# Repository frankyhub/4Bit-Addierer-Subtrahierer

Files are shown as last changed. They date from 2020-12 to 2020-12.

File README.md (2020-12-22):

# 4Bit-Addierer-Subtrahierer

## Frontplatte


## Funktion
Ist der Schalter Add in Position oben, werden die 4 Bits a1-a8 mit den Bits b1-b8 addiert und das Ergebnis mit den LEDs S1 - S16 angezeigt.
Ist der Schalter Add in Position unten, werden die 4 Bits b1-b8 von den Bits a1-a8 subtrahiert und das Ergebnis mit den LEDs S1 - S16 angezeigt.

## Schaltplan
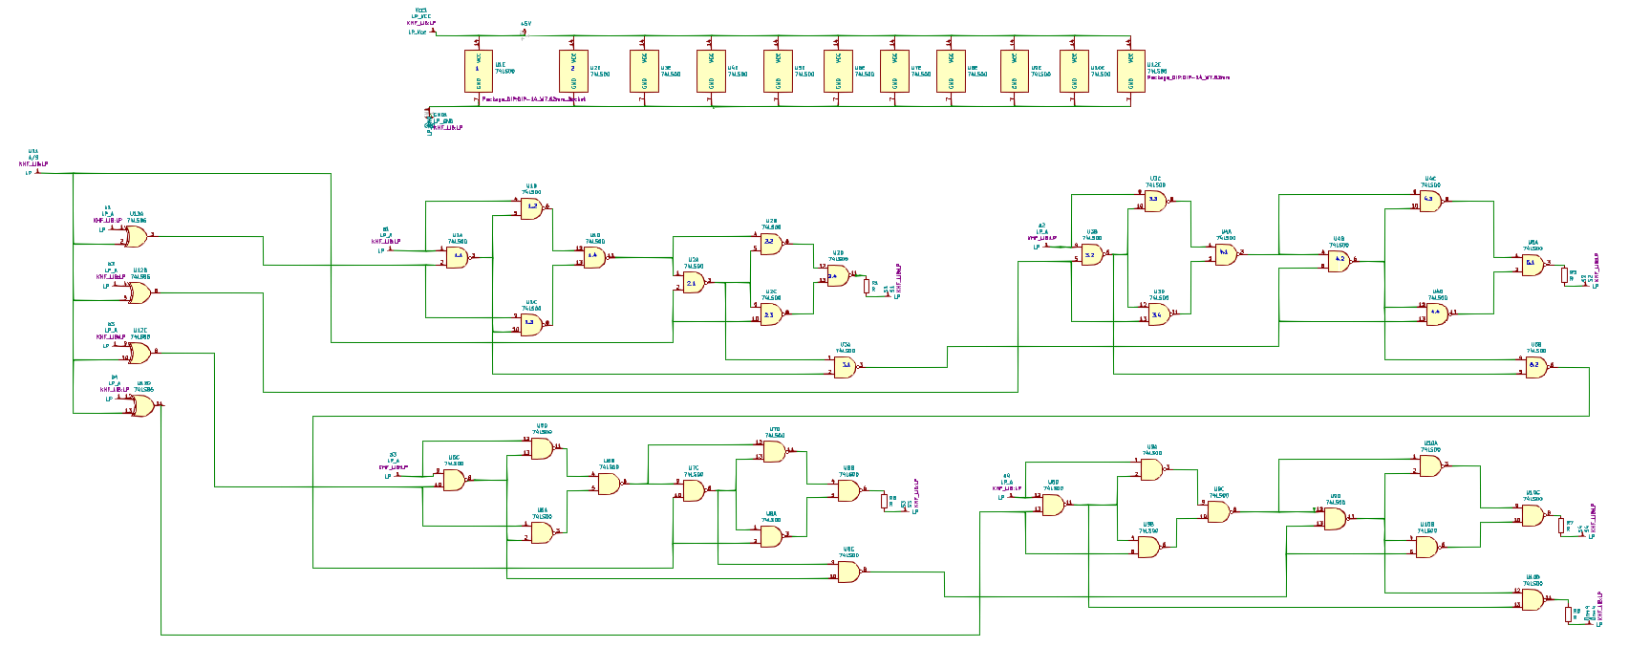
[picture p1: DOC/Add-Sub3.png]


## Platine


## Dokumentation
[Link zur Dokumentation](https://github.com/frankyhub/4Bit-Addierer-Subtrahierer/blob/main/DOC/4-Bit-Add-Sub-Dokumentation.pdf)

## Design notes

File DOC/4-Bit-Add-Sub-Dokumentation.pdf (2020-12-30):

### 4-Bit-Addierer-Subtrahierer

### Dokumentation

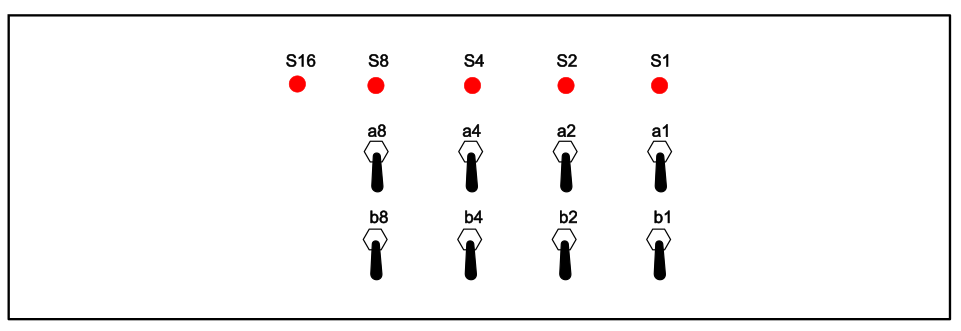
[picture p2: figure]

4-Bit-Addierer-Subtrahierer

Erstellt: | KHF | Version: | V1.0 | Seite 2 von 8

D:\gittemp\4Bit-Addierer\4-Bit-Add-Sub-Dokumentation.docx

Beschreibung

Der 4-Bit-Addierer addiert die Bits a1-a8 mit b1-b8 und zeigt die Summe im dualen Zahlensystem mit den LEDs S1-S16 an. Die Beschriftung der Schalter und LEDs resultiert aus der Wertigkeit der Schalter und der LEDs.

Schalter | Wertigkeit binär | Wertigkeit dezimal
a1 | 2 0 | 1
a2 | 2 1 | 2
a4 | 2 2 | 4
a8 | 2 3 | 8
Schalter | Wertigkeit binär | Wertigkeit dezimal
b1 | 0 2 | 1
b2 | 2 1 | 2
b4 | 2 2 | 4
b8 | 3 2 | 8
LED Summe | Wertigkeit binär | Wertigkeit dezimal
S1 | 2 0 | 1
S2 | 2 1 | 2
S4 | 2 2 | 4
S8 | 2 3 | 8
S16 | 4 2 | 16

Schalterstellung unten = 0, Schalterstellung oben = 1

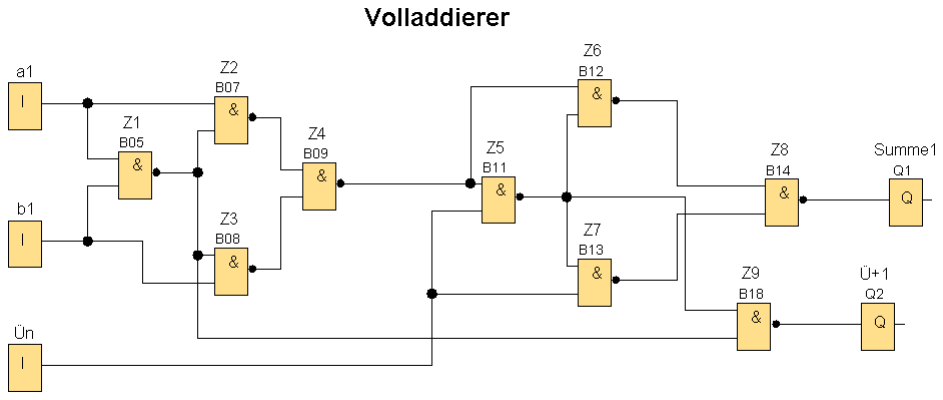
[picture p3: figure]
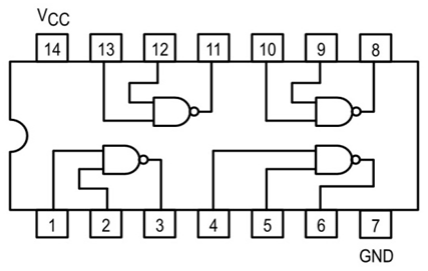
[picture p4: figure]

Erstellt: | KHF | Version: | V1.0 | Seite 3 von 8

Der 4-Bitt-Addierer besteht aus vier Volladdierer:

Ün | a | b | Summe | Ün+1
0 | 0 | 0 | 0 | 0
0 | 0 | 1 | 1 | 0
0 | 1 | 0 | 1 | 0
0 | 1 | 1 | 0 | 1
1 | 0 | 0 | 1 | 0
1 | 0 | 1 | 0 | 1
1 | 1 | 0 | 0 | 1
1 | 1 | 1 | 1 | 1
Funktionstabelle eines Volladdierers

Der 4-Bit-Addierer wurde mit zehn TTL (Transistor-Transistor-Logik) ICs SN74LS00N aufgebaut:

Datasheet SN74LS00N - 4 NAND-Gatter

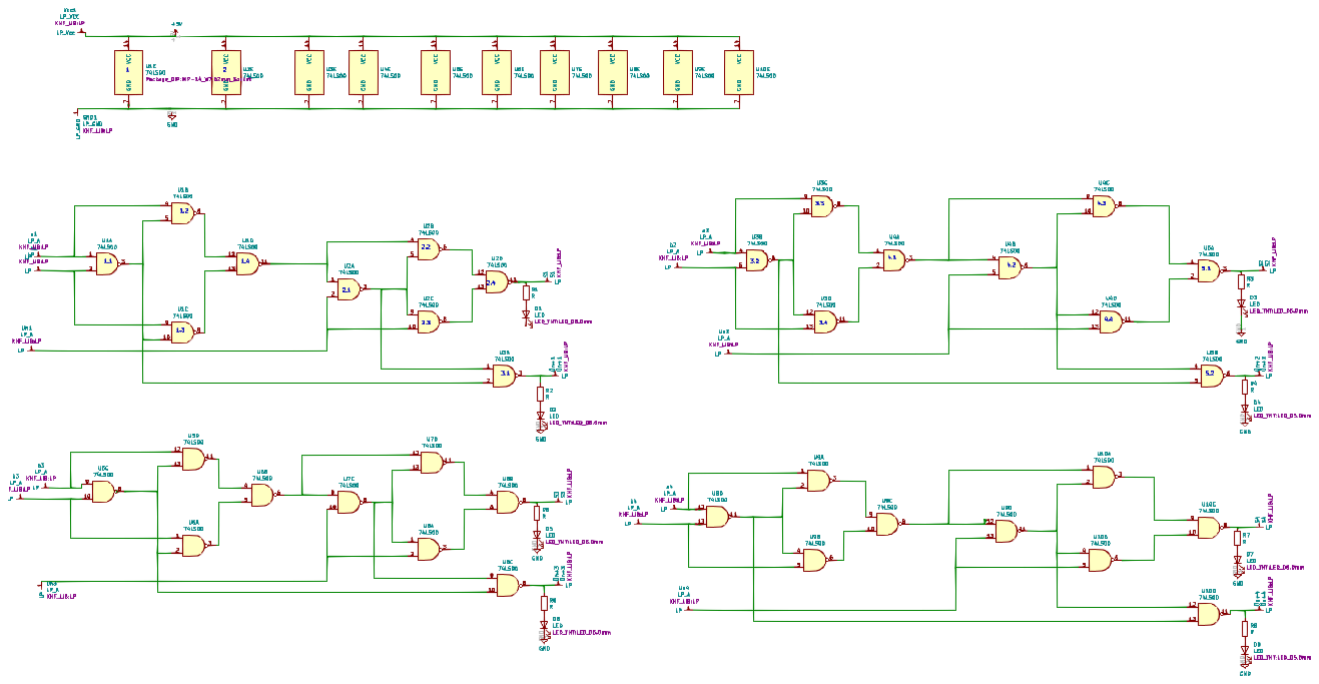
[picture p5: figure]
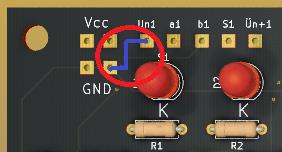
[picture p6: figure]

Erstellt: | KHF | Version: | V1.0 | Seite 4 von 8
Eingang 1 | Eingang 2 | Ausgang
0 | 0 | 1
0 | 1 | 1
0 | 0 | 1
1 | 1 | 0
Funktionstabelle NAND SN74LS00N

Damit die Bits a1-a8 mit den Bits b1-b8 addiert werden können, benötigt man vier Volladdierer.

Schaltplan des 4-Bit-Addierers

Bestehend aus vier Volladdierer

Hinweis: TTL-Bausteine haben die Eigenschaft, einen offenen Eingang als logisch 1 zu erkennen. Deshalb muss der Übertrag Un1 des ersten Addierers mit logisch 0 beschalten werden. Dies erfolgte auf der Platine mit einer Drahtbrücke.

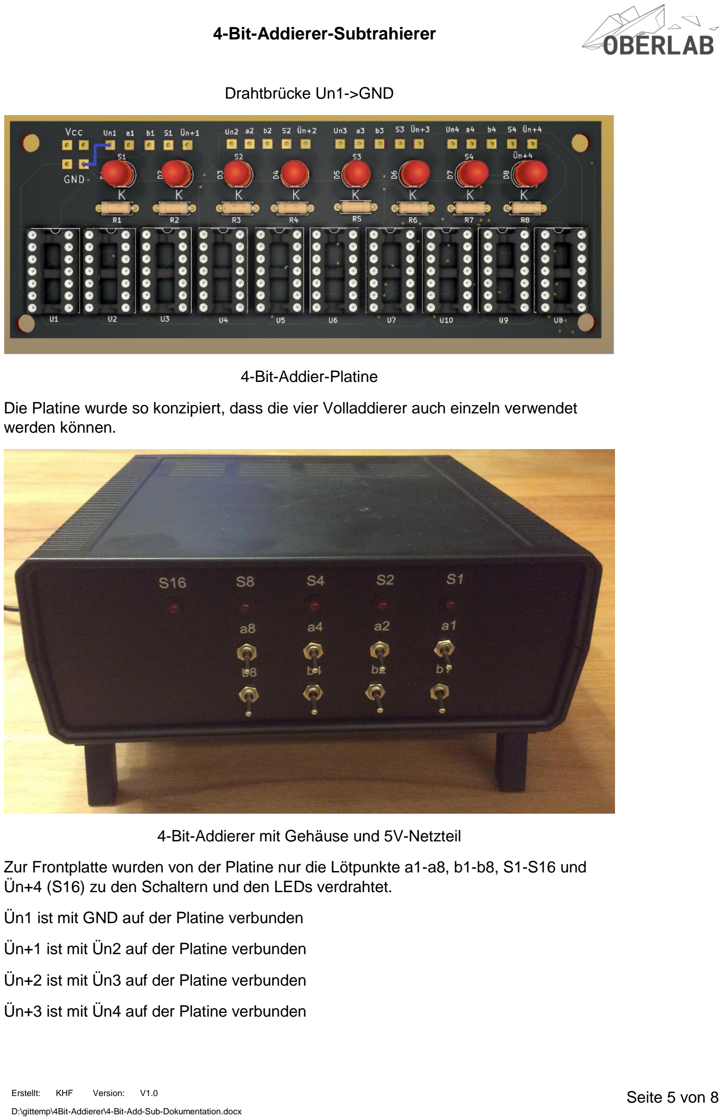
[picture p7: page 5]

Erstellt: | KHF | Version: | V1.0 | Seite 5 von 8

Drahtbrücke Un1->GND

4-Bit-Addier-Platine

Die Platine wurde so konzipiert, dass die vier Volladdierer auch einzeln verwendet werden können.

4-Bit-Addierer mit Gehäuse und 5V-Netzteil

Zur Frontplatte wurden von der Platine nur die Lötpunkte a1-a8, b1-b8, S1-S16 und Ün+4 (S16) zu den Schaltern und den LEDs verdrahtet.

Ün1 ist mit GND auf der Platine verbunden

Ün+1 ist mit Ün2 auf der Platine verbunden

Ün+2 ist mit Ün3 auf der Platine verbunden

Ün+3 ist mit Ün4 auf der Platine verbunden

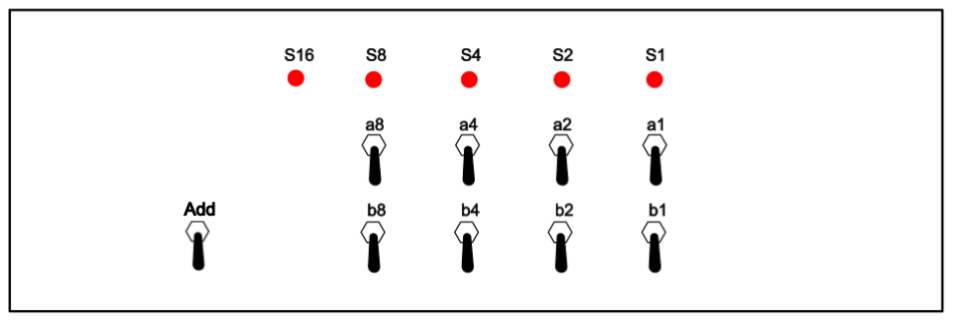
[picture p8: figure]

Erstellt: | KHF | Version: | V1.0 | Seite 6 von 8

Das 5V-Steckenetzteil ist direkt mit der Platine Vcc und GND verbunden. Der Anschluss des Steckernetzteils ist mit einer PNG-Verschraubung und einer Zugentlastung nach außen geführt.

Erweiterung zum Subtrahierer positiver Zahlen

Der 4-Bit-Addierer wurde mit einem Kippschalter und einer EXOR-Eingangsbeschaltung zum Subtrahierer erweitert. Ist der Kippschalter Add in der Position oben funktioniert der Addierer vor beschrieben als 4-Bitt-Adierer. Die Bits a1 – a8 werden mit den Bits b1 – b8 addiert und die Summe mit den LEDs S1 – S16 angezeigt.

Wird der Kippschalter Add nach unten geschalten, funktioniert der 4-Bit-Addierer als Subtrahierer. Die Bits b1 – b8 werden von den Bits a1 – a8 subtrahiert und das Ergebnis mit den LEDs S1 – S16 angezeigt.

Einer Subtraktion von Dualzahlen liegt eine Addition zugrunde. Dabei wird beim Subtrahend (b1 – b8) der Kehrwert gebildet und mit dem Minuend (a1 – a8) addiert. Diesen Vorgang nennt man Einerkompliment bilden. Im Anschluss wird dem Ergebnis eine 1 addiert.

Erstellt: | KHF | Version: | V1.0 | Seite 7 von 8

Beispiel:

Subtraktion | Wertigkeit | 16 | 8 | 4 | 2 | 1
12 | 12 | 0 | 1 | 1 | 0 | 0
-7 | 7 | 0 | 0 | 1 | 1 | 1
Einerkomplement | Einerkomp. | 1 | 1 | 0 | 0 | 0
Addition | Add | 0 | 0 | 1 | 0 | 0
+1 | +1 | | | | | 1
| Ergebnis | 0 | 0 | 1 | 0 | 1
17 | 17 | 1 | 0 | 0 | 0 | 1
-9 | -9 | 0 | 1 | 0 | 0 | 1
Einerkomplement | Einerkomp. | 1 | 0 | 1 | 1 | 0
Addition | Add | 0 | 0 | 1 | 1 | 1
+1 | +1 | | | | | 1
| Ergebnis | 0 | 1 | 0 | 0 | 0
15 | 15 | 0 | 1 | 1 | 1 | 1
-10 | 10 | 0 | 1 | 0 | 1 | 0
Einerkomplement | Einerkomp. | 1 | 0 | 1 | 0 | 1
Addition | Add | 0 | 0 | 1 | 0 | 0
+1 | +1 | | | | | 1
| Ergebnis | 0 | 0 | 1 | 0 | 1

Die Negation der Minuenden wurde Schaltungstechnisch mit einem EXOR an den Eingängen von b1 – b8 realisiert. Die +1 Addition erfolgt beim ersten Volladdierer am Eingang Un1. Dieser Eingang wird bei einer Subtraktion logisch 1 beschalten.

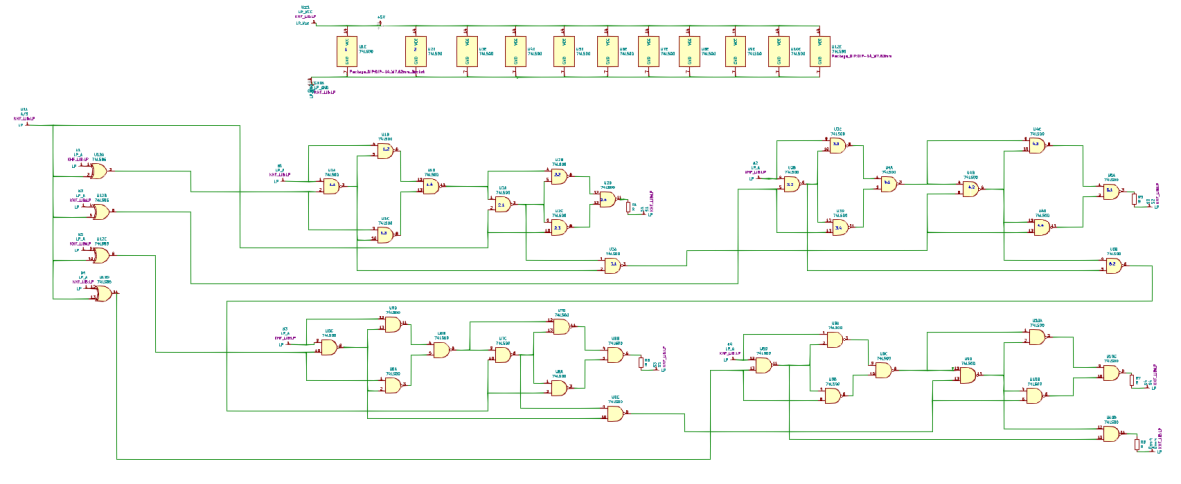
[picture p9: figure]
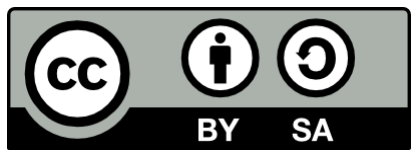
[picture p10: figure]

Erstellt: | KHF | Version: | V1.0 | Seite 8 von 8

Schaltplan des 4-Bit-Addierers mit der Eingangsbeschaltung für den Subtrahierer

Die Platine ist mit dem Open Source Programm KiCad erstellt worden.

Link: https://kicad.org/download/

Die Frontplatte wurde mit dem Open Source Programm Inkscape erstellt.

Link: https://inkscape.org/de/release/inkscape-1.0.1/

Der Link für den download der Dateien: https://github.com/frankyhub/4Bit-Addierer

Der 4-Bitt-Addierer wurde erstell im

FabLab Oberland e.V.

Tölzer Str. 3A,

83703 Gmund am Tegernsee

Lizenz:

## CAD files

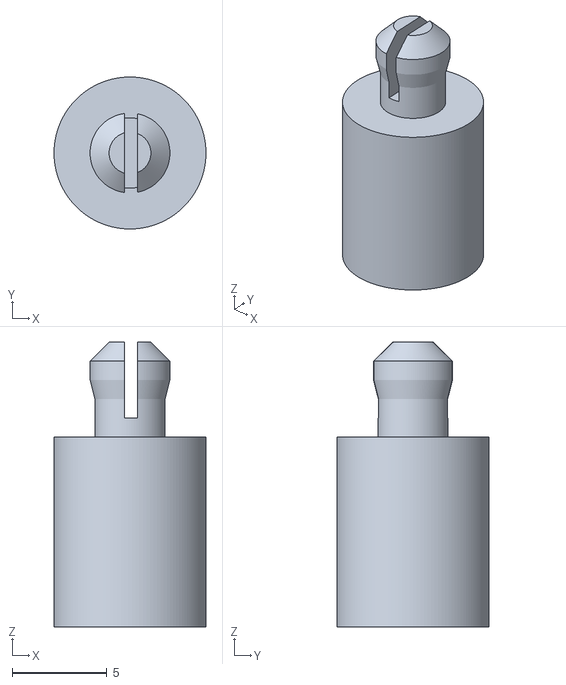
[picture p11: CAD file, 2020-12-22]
Slicer/PIN_4mm.stl
8.00 x 8.00 x 15.0

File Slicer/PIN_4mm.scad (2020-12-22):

$fn=130;

D_sock=8; //Sockeldurchmesser
D_kubb=4.2;  //Knubbeldurchmesser
H_sock=10; //Sockelhöhe
//Schaftdurchmesser=Knubbeldurchmesser-0.5

//Sockel
H=H_sock-6;color("Gray")
translate([0,0,H*-1])
cylinder (h=H_sock, d=D_sock);

difference(){

//Knubbl
color("Silver")       
union(){
translate([0,0,10])
cylinder (h=1, d1=D_kubb, d2=D_kubb-2);
translate([0,0,8])
cylinder (h=1, d1=D_kubb-0.5, d2=D_kubb);
translate([0,0,9])
cylinder (h=1, d1=D_kubb, d2=D_kubb);
//Schaft
translate([0,0,6])
cylinder (h=2, d=D_kubb-0.5);   
}


//Einschnitt
translate([-0.3,-2.5,7])
 cube([0.7,5,7]);
}
